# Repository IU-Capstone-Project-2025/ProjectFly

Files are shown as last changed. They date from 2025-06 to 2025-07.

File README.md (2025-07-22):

# **Project Fly** 

🚀 *Reed Switch-Based Liquid Level Sesnor.*

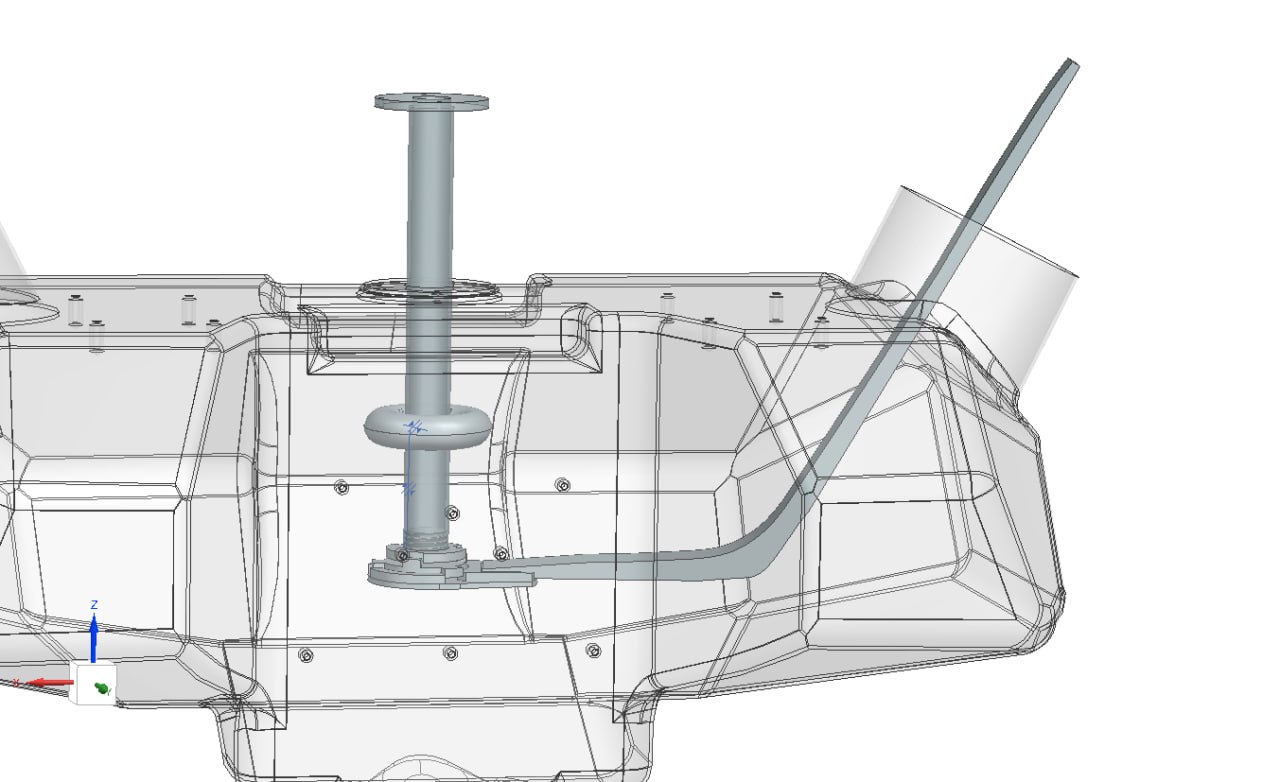
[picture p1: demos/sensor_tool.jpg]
Sensor with assembly tool inside of a tank


## 📌 Overview
A compact reed switch-based liquid level sensor designed for UAV-mounted tanks for agrochemicals. The sensor uses a magnetic float and hermetically sealed reed switches to reliably detect liquid levels in harsh environments.

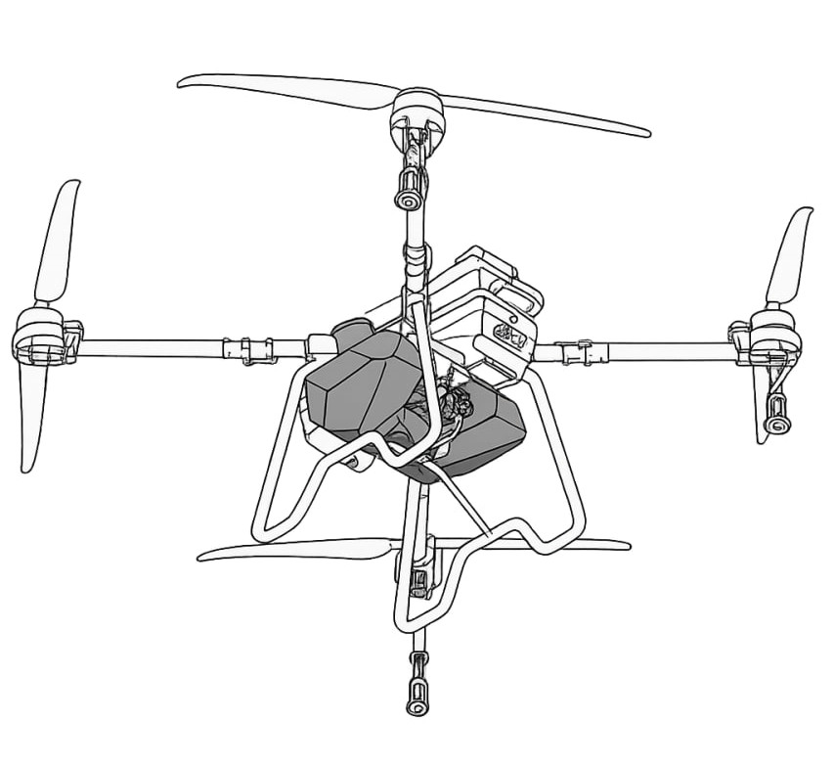
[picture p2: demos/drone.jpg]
Drone with tank


## 🔧 Key Features 
- **No calibration needed**: float does not depend on liquid type
- **Robust signal**: sliding window median filter
- **Easy to install**: special assembling tool
- **Low power consumption**

## 🛠️ Hardware 
- **Key components**: Reed Switches 4x28 mm NC
- **Microcontroller**: STM32F103C8T6
- **Output**: Digital signal (UART)
- **Power**: 3.3V-5V

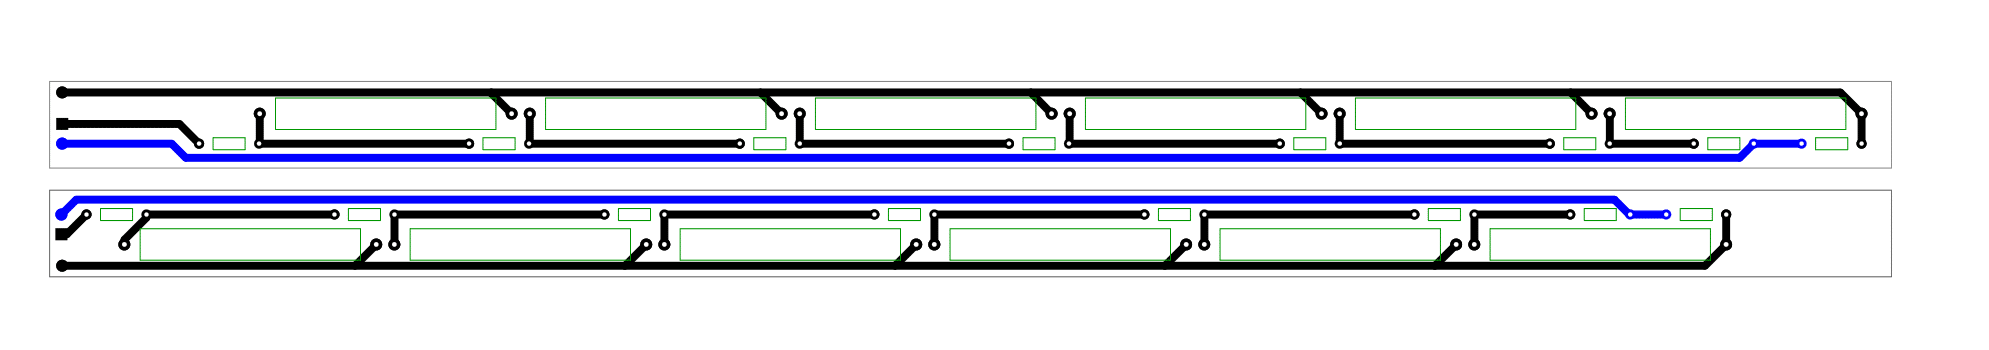
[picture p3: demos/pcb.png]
PCB


## 📚 Documentation
- [**Schematics sheet**](docs/schematics.pdf)
- [**Schematics description**](docs/schematics.md)
- [**Assembly guide**](docs/assembly.md)

## 📂 Project Structure
```
ProjectFly
├── cad         # 3D models
├── demos       # Demonstrations videos and images
├── docs        # Project documentation
├── firmware    # Embedded code
│   ├── arduino # Arduino-compatible firmware (for prototyping)
│   └── stm32   # STM32-optimized firmware (production version)
├── hardware    # Electronics design files
│   └── pcb     # PCB schematics and layouts
└── tests       # Validation scripts
```

## 👥 Team Members
### Hardware
- **Dmitriy Vizitei** - team leader, prototyping
- **Senya Belykh** - schematics, PCB design
- **Anas Hamrouni** - CAD modeling & design
### Software
- **Dmitry Ryabov** - programming, testing
### Documentation 
- **Andrew Pavlov** - documentation, reports

## 🛠 **Build && Install Guide**  
**Docker** ([Install Guide](https://docs.docker.com/engine/install/)) <br>
In terminal:  
1) `docker-compose build` 
2) `docker-compose up`

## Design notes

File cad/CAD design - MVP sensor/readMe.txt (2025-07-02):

Here is name & description of parts of the floating mechanism, parts consisting of multiple parts are grouped together.
In the directory you find two assembly files and separate part files.
rodTankAssembly is the global assembly file containing all the parts.

Float: (consists of two parts to be assembled with snap joints, housing up to 4 magnets)
- part1name: float: first part of the float
- part2name: float - Copie: second part of the float

Bottom cap:
- part3name: bottomcap: serves to block float from escaping from the rod column

Sensor rod (shaft)
- part4name: rod2: main vertical column of the sensor to guide the float and serves as housing of IC with reed sensors (still low fidelity, no fixing of IC yet)

Assembling tool (consists of three parts to be glued together): serves to fix the bottom cap
- part5name: toolHandler: first part of assembling tool
- part6name: toolHandle2: second part of assembling tool
- part7name: tool: third part of assembling tool

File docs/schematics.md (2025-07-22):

# Electrical Circuit
The electrical circuit of the device consists of six normally closed (NC) reed switches (4x28 mm) that connect power and signal lines. A 10 kΩ resistor is placed between each reed switch to detect which one is closed using the voltage divider rule. A current-limiting resistor is placed before the first reed switch to prevent a short circuit. A separating resistor is placed after the last reed switch to distinguish between the last reed switch being closed and no switch being closed. A 100 kΩ resistor is connected between the signal line and ground to suppress contact bouncing. The circuit operates at 3.3 V.

# PCB Design
The printed circuit board (PCB) has a length matching the tank length (234 mm), which fits six reed switches with 0.85 mm spacing between leads, and a minimum possible width of 11 mm. The trace width is 1 mm for reliability and ease of manufacturing. The final device consists of two identical PCBs, but with the reed switches offset by 14 mm (half the length of a reed switch) relative to each other. This allows dual verification of magnet position and eliminates blind spots between reed switches on the opposite PCB.

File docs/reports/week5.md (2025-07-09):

---
title: "Week #5"
---

# **Week #5**

## Team

### **Team Members**

| Team Member							| Telegram Alias	| Email Address 					| Track												| Responsibilities |
|---|---|---|---|---|
| Dmitriy Vizitei (Lead)				| @otkisaev			| d.vizitei@innopolis.university 	| Low level (embedded) + Electric circuit engineer + testing  | Project coordination, task delegation, programming and testing prototypes |
| Senea Belykh							| @SenyaZenya		| s.belykh@innopolis.university		| Low level (embedded) + Electric circuit engineer	| Programming and testing prototypes |
| Dmitry Ryabov							| @theDioxider		| d.ryabov@innopolis.university 	| Low level (embedded) 								| Programming |
| Anas Hamrouni							| @reachnasta		| a.hamrouni@innopolis.university | Design engineer 									| Designing 3D models |
| Andrew Pavlov							| @chaleshka_0		| and.pavlov@innopolis.university	| Tech writer 										| Document the work and write reports |

## Feedback

Through Alexander Maloletov (Director of the Robotics Development Center in Innopolis), we agreed that upon completion of the order, the project participants will receive a lump sum payment.

## Iteration & Refinement

### Performance & Stability

When the magnet slides post reed switches, there is a chance to get a value equal to 0. This is due to the current solution and design. There is a metric associated with the gaps between switches. <br />
An iteration solution would be to reduce the size of reed switches to such an extent that a negligibly small gap between the switches is reached, which would guarantee a constant and unambiguously set position of the float.

# Weekly commitments

## Individual contribution of each participant

| Member					| Contribution					|
|---|---|
| Dmitriy Vizitei			| Assembly of a product, communication, testing: [photo](https://drive.google.com/file/d/11ErTu5s1axHB51JZw7vPIAQcNcZdXoS1/view?usp=drive_link), [video 1](https://drive.google.com/file/d/17mmQQElqiJNetmurcGpcXXFE-Ebcmi8j/view?usp=drive_link), [video 2](https://drive.google.com/file/d/1X96Me4vulu15EC3oLPyxjKNYTdaBQLdP/view?usp=drive_link), [video 3](https://drive.google.com/file/d/1RMR0l2JPTSWMmnUTkXt8X2qB1T35l_1s/view?usp=drive_link) |
| Senea Belykh				| [Littel change design of board and design of a microcontroller board](https://github.com/IU-Capstone-Project-2025/ProjectFly/commit/9250cefd38d36df9182ef802b712d2c060db03d2) | 
| Dmitry Ryabov				| Determining reed switch based on voltage: [photo](https://drive.google.com/file/d/1ix-wG_TddyOyOhTqer4dDWPdwUh-kQOK/view?usp=drive_link), [commit 1](https://github.com/IU-Capstone-Project-2025/ProjectFly/commit/e2bc04ccc3fc08e8e42fd3654ed2149dc4a043e4), [commit 2](https://github.com/IU-Capstone-Project-2025/ProjectFly/commit/748511da521208b3848574d846316bceeffb3a55) |
| Anas Hamrouni				| [PCB design + review of dimensions](https://github.com/IU-Capstone-Project-2025/ProjectFly/commit/1565ed656107ac8c0a5cf2ffb28c307ee85f2cba) |
| Andrew Pavlov				| [5nd week report.](https://github.com/IU-Capstone-Project-2025/ProjectFly/blob/main/docs/reports/week5.md) |

## Plan for Next Week

- Build the microcontroller board
- Complete the prototype assembly
- Сontact the customer to confirm our product solution

## Confirmation of the code's operability

We confirm that the code in the main branch:
- [x] In working condition.
- [x] Run via docker-compose (or another alternative described in the `README.md`).

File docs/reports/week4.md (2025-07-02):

---
title: "Week #4"
---

# **Week #4**

## Team

### **Team Members**

| Team Member							| Telegram Alias	| Email Address 					| Track												| Responsibilities |
|---|---|---|---|---|
| Dmitriy Vizitei (Lead)				| @otkisaev			| d.vizitei@innopolis.university 	| Low level (embedded) + Electric circuit engineer + testing  | Project coordination, task delegation, programming and testing prototypes |
| Senea Belykh							| @SenyaZenya		| s.belykh@innopolis.university		| Low level (embedded) + Electric circuit engineer	| Programming and testing prototypes |
| Dmitry Ryabov							| @theDioxider		| d.ryabov@innopolis.university 	| Low level (embedded) 								| Programming |
| Anas Hamrouni							| @reachnasta		| a.hamrouni@innopolis.university | Design engineer 									| Designing 3D models |
| Andrew Pavlov							| @chaleshka_0		| and.pavlov@innopolis.university	| Tech writer 										| Document the work and write reports |

## CI/CD

During CI/CD, we encountered the problem that the github workflow does not have a compilation environment for our product, so we did manual tests on cubeIDE.

### Links to CI/CD configuration files

https://github.com/IU-Capstone-Project-2025/ProjectFly/blob/main/.github/workflows/c-linter.yaml

## Vibe Check

The team leader is on sick leave, and the rest of the team is healthy. <br />
Due to logistical problems, the laser needed for the work was delivered to us very late in time for the deadline, which caused a lot of stress during its setup and operation in the last hours before the deadline.

# Weekly commitments

## Individual contribution of each participant

| Member					| Contribution					|
|---|---|
| Dmitriy Vizitei			| Testing: [photo 1](https://drive.google.com/file/d/11sWm9Eje6SpBsuDrlUKM9gq9MjP24NQu/view?usp=drive_link), [photo 2](https://drive.google.com/file/d/1dNQqF_wJioakaVgUDXrWjnx1O2QSEEL4/view?usp=drive_link); laying out the board using laser: [video 1](https://drive.google.com/file/d/1wMU_KEni9PQ2VG3ThoixvVIlINiCmWOo/view?usp=drive_link), [video 2](https://drive.google.com/file/d/13v9Dhd8rFhSDY7FK-wtBonQAqTI9EYGV/view?usp=drive_link), [photo](https://drive.google.com/file/d/1k83NPXRmFJaZUlnCxQowFRZGzRzlfGT7/view?usp=drive_link) |
| Senea Belykh				| The renewed version of the board: [screenshot 1](https://drive.google.com/file/d/1f35pPph8MtAH_zsE1N_wpZU_w1E1n0Zs/view?usp=drive_link), [screenshot 2](https://drive.google.com/file/d/1TuTwNzNpZY1UzZ-rh-VTb_SV1s4rwtpJ/view?usp=drive_link), [files](https://github.com/IU-Capstone-Project-2025/ProjectFly/commit/5295f774d12a0047f9f7b59432f5d1f2cc4458eb); [testing](https://drive.google.com/file/d/1BBwjxaTWTiUZHPBcxWp0rQVh082nHvK7/view?usp=drive_link) |
| Dmitry Ryabov				| [CI/CD](https://github.com/IU-Capstone-Project-2025/ProjectFly/blob/main/.github/workflows/c-linter.yaml), [filter (embedded development)](https://github.com/IU-Capstone-Project-2025/ProjectFly/commit/508749f63c032bdbdd70469d089fd19ae9c99970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) |
| Anas Hamrouni				| The design of lever, the renewed design of float, design of the rod: [photo 1](https://drive.google.com/file/d/11sWm9Eje6SpBsuDrlUKM9gq9MjP24NQu/view?usp=drive_link), [photo 2](https://drive.google.com/file/d/1dNQqF_wJioakaVgUDXrWjnx1O2QSEEL4/view?usp=drive_link), [files](https://github.com/IU-Capstone-Project-2025/ProjectFly/commit/2ea619bedeee6b55bfc94a4936219a47339772bb) |
| Andrew Pavlov				| [4nd week report.](https://github.com/IU-Capstone-Project-2025/ProjectFly/blob/main/docs/reports/week4.md) |

## Plan for Next Week

- Layout the final pcb using laser
- Assemble the renewed configuration of a product
- Connect the pcb to the layout of reed switches

## Confirmation of the code's operability

We confirm that the code in the main branch:
- [X] In working condition.
- [X] Run via docker-compose (or another alternative described in the `README.md`).

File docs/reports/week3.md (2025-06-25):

---
title: "Week #3"
---

# **Week #3**

## Team

### **Team Members**

| Team Member							| Telegram Alias	| Email Address 					| Track												| Responsibilities |
|---|---|---|---|---|
| Dmitriy Vizitei (Lead)				| @otkisaev			| d.vizitei@innopolis.university 	| Low level (embedded) + Electric circuit engineer  | Project coordination, task delegation, programming and testing prototypes |
| Senea Belykh							| @SenyaZenya		| s.belykh@innopolis.university		| Low level (embedded) + Electric circuit engineer	| Programming and testing prototypes |
| Dmitry Ryabov							| @theDioxider		| d.ryabov@innopolis.university 	| Low level (embedded) 								| Programming |
| Anas Hamrouni							| @reachnasta		| a.hamrouni@innopolis.university | Design engineer 									| Designing 3D models |
| Andrew Pavlov							| @chaleshka_0		| and.pavlov@innopolis.university	| Tech writer 										| Document the work and write reports |

## Implemented MVP features
- Functional fragment of sensor
- Programmed stm microcontroller that read, process and output signals from the sensor
- 3d model of sensor road and float with assembly tool
- Finished PCB layout

## Demonstration of the working MVP

https://github.com/user-attachments/assets/4fa052ff-b1a2-4596-b420-3efbf912d3e5

## Internal demo

The demonstration shows a fragment of the sensor consisting of two parallel circuits with reed switches. The second circuit is needed to validate the readings. Readings from two circuits are displayed separately on the screen.
In the future, with the help of a filter and two readings, a smooth and reliable output of values will be realized.

# Weekly commitments

## Individual contribution of each participant

| Member					| Contribution					|
|---|---|
| Dmitriy Vizitei			| [Build and testing of the float sensor](https://github.com/IU-Capstone-Project-2025/ProjectFly/blob/main/docs/reports/week3_demo.mp4)	|
| Senea Belykh				| Design of a printing board model: [.dip file of model](https://drive.google.com/file/d/1kAshYWK63EGtSO8ugL8LIpLLuq3zHijo/view?usp=drive_link), [Screenshot 1](https://drive.google.com/file/d/1b59gKXb-_gpLtJmoub-71Or28Qxjg9nt/view?usp=drive_link), [Screenshot 2](https://drive.google.com/file/d/1cMnjLT8AdKEfaEngB_d79zmb4BKwSN_p/view?usp=drive_link), [Screenshot 3](https://drive.google.com/file/d/19lfl12A_gvJT9DxeMLiNG9lB-w_u033m/view?usp=drive_link), [Screenshot 4](https://drive.google.com/file/d/15qXjzGLoRry6YyHDq0xQBWc0gWb6dqjc/view?usp=sharing)	|
| Dmitry Ryabov				| [Data processing and multitasking implementation](https://github.com/IU-Capstone-Project-2025/ProjectFly/commit/427cdca47f92fd35336689fed5b88d71be1657ca)	|
| Anas Hamrouni				| CAD design for MVP float sensor and and its installation: [Screenshot 1](https://drive.google.com/file/d/1yXhJFeNlo0ktXdDd30qICJDR3P5ZgBRc/view?usp=drive_link), [Screenshot 2](https://drive.google.com/file/d/1Cs98SicpZ4TfVprqYWIeNAE5lt_2MkrX/view?usp=drive_link), [Screenshot 3](https://drive.google.com/file/d/1mO2JWQUNWl51_XnYHGpag1vgucJC9s4t/view?usp=drive_link), [Screenshot 4](https://drive.google.com/file/d/1EVLHVlt_bsYl2PFsscmXYxY9q6P1DE29/view?usp=sharing), [Screenshot 5 (The brown color is one piece to be assembled as a tool) ](https://drive.google.com/file/d/1q62NgHWZDSAhbYw4ZfM8Jk9xgEBASD9l/view?usp=drive_link), [archive with models of parts](https://drive.google.com/file/d/1Xy0XBJnHxUWf5-DdJJCfNiPBmoh62PsU/view?usp=drive_link)	|
| Andrew Pavlov				| [3nd week report.](https://github.com/IU-Capstone-Project-2025/ProjectFly/blob/main/docs/reports/week3.md)	|

## Plan for Next Week

- Lay out the board
- Prepare MVP 
- Test the MVP 
- Analyze the numerical data after the test and consider alternative approaches based on it

## Confirmation of the code's operability

We confirm that the code in the main branch:
- [X] In working condition.
- [X] Run via docker-compose (or another alternative described in the `README.md`).

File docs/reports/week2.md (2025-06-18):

---
title: "Week #2"
---

# **Week #2**

## Team

### **Team Members**

| Team Member							| Telegram Alias	| Email Address 					| Track												| Responsibilities |
|---|---|---|---|---|
| Dmitriy Vizitei (Lead)				| @otkisaev			| d.vizitei@innopolis.university 	| Low level (embedded) + Electric circuit engineer  | Project coordination, task delegation, programming and testing prototypes |
| Senea Belykh							| @SenyaZenya		| s.belykh@innopolis.university		| Low level (embedded) + Electric circuit engineer	| Programming and testing prototypes |
| Dmitry Ryabov							| @theDioxider		| d.ryabov@innopolis.university 	| Low level (embedded) 								| Programming |
| Anas Hamrouni							| @reachnasta		| a.hamrouni@innopolis.university | Design engineer 									| Designing 3D models |
| Andrew Pavlov							| @chaleshka_0		| and.pavlov@innopolis.university	| Tech writer 										| Document the work and write reports |

## Detailed Requirements Elaboration

### Prioritized backlog

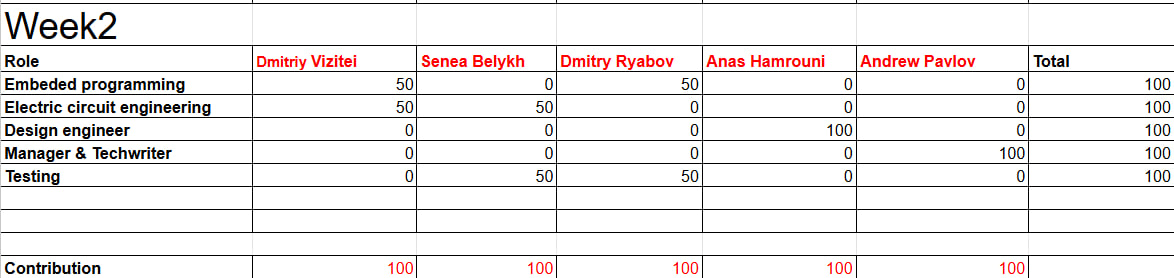
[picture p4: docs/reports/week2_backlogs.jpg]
Backlog


More about that check [here (Individual contribution of each participant)](#individual-contribution-of-each-participant)

## Project specific progress

### Embeded programming
 Managed to read measurements from the new prototype of sensor based on stm and reed configuration.
 
 ##### *Links*:
 - [video](https://drive.google.com/file/d/1tDcIl50uG16ULDPnCgHA8W5yxoyPV0qn/view?usp=drive_link)
 - [commit 1](https://github.com/IU-Capstone-Project-2025/ProjectFly/commit/f93522ddb09a518377ced257cc0ca16c6add2b1f)
 - [commit 2](https://github.com/IU-Capstone-Project-2025/ProjectFly/commit/e084e92ea104956475aa945d4a9cade105bdb73c)

<br/>
<br/>

### Electric circuit engineering
 Build the prototype based on reed switch

 ##### *Links*:
 - [schema](https://drive.google.com/file/d/1HSIqzhiNN1nDQKsxPV_4JEf09wa4fA4u/view?usp=drive_link)
 - [builded scheme](https://drive.google.com/file/d/1XPFuSay2cHmU6ANBiu6EqrAynp7D94Xp/view?usp=drive_link)

<br/>
<br/>

### Design engineer
#### 1. Define functional and user requirements of the rod: 
- Simple & 3d printable geometry
- Respect shape dimensions to fit the tank
- Ease of installation
- Safety and efficiency of use 

#### 2. Sketching the model:
- Ensure to provide 3d printable geometry
- Design robust shape despite small dimension
- Added screw threading to fix small shape easily without special tools
- Built a safe and efficient solution by avoiding changing shape of the tank and requiring simple drilling to place the rod with keeping the tank sealed.

 ##### *Links*:
 - [Screenshot 1](https://drive.google.com/file/d/1L9kOTLYdC7mNY9wW7mFL8em9XUuGiUwT/view?usp=drive_link)
 - [Screenshot 2](https://drive.google.com/file/d/1gHUbHs0_TNIRGTnDAtzoiVuIBHDGAfwj/view?usp=drive_link)
 - [file 1](https://drive.google.com/file/d/1nWXCW6NQID7t2FsywJsJTqwMTLUtGRwR/view?usp=drive_link)
 - [file 2](https://drive.google.com/file/d/1oYTtV5gna4aSWWOiLER292Gw-_cxK6or/view?usp=drive_link)

<br/>
<br/>

### Testing
Testing prototypes

 ##### *Links*:
 - [video](https://drive.google.com/file/d/1Viy6Q0saY_VFVdwo4Y1-elQ6-YxZEiJ0/view?usp=drive_link)
 - [schema](https://drive.google.com/file/d/1ElpVAXV8CM7XJ8-GV-PHEquDS3nxepYG/view?usp=drive_link)
 - [commit](https://github.com/IU-Capstone-Project-2025/ProjectFly/commit/0b85bc00f4705b56a24b432282a6310fd2ffb4f2)
<br/>
<br/>

### Manager
Clarification from the customer: *He prefers that we do not go into the mathematical model of the drone to solve this problem.*

<br/>
<br/>

# Weekly commitments

## Individual contribution of each participant

| Member					| Contribution					|
|---|---|
| Dmitriy Vizitei			| [Planning the work](https://drive.google.com/file/d/1gMR6xSsX36B3hY9kbOCmtgMwcS75k4nC/view?usp=drive_link), testing one of the prototypes: [video](https://drive.google.com/file/d/1Viy6Q0saY_VFVdwo4Y1-elQ6-YxZEiJ0/view?usp=drive_link), [schema](https://drive.google.com/file/d/1ElpVAXV8CM7XJ8-GV-PHEquDS3nxepYG/view?usp=drive_link), [commit](https://github.com/IU-Capstone-Project-2025/ProjectFly/commit/0b85bc00f4705b56a24b432282a6310fd2ffb4f2).	|
| Senea Belykh				| Build the prototype based on [reed switch](https://en.wikipedia.org/wiki/Reed_switch): [schema](https://drive.google.com/file/d/1HSIqzhiNN1nDQKsxPV_4JEf09wa4fA4u/view?usp=drive_link), [builded scheme](https://drive.google.com/file/d/1XPFuSay2cHmU6ANBiu6EqrAynp7D94Xp/view?usp=drive_link).	|
| Dmitry Ryabov				| Managed to read measurements from the new prototype of sensor based on stm and reed configuration: [video](https://drive.google.com/file/d/1tDcIl50uG16ULDPnCgHA8W5yxoyPV0qn/view?usp=drive_link), [commit 1](https://github.com/IU-Capstone-Project-2025/ProjectFly/commit/f93522ddb09a518377ced257cc0ca16c6add2b1f), [commit 2](https://github.com/IU-Capstone-Project-2025/ProjectFly/commit/e084e92ea104956475aa945d4a9cade105bdb73c). [Geometric implementation of first prototype](https://drive.google.com/file/d/1gd1Zq0q2f0FHHBFnNQjB2sdK0_8jG9m8/view?usp=drive_link). 	|
| Anas Hamrouni				| Sensor installation design: [Screenshot 1](https://drive.google.com/file/d/1L9kOTLYdC7mNY9wW7mFL8em9XUuGiUwT/view?usp=drive_link), [Screenshot 2](https://drive.google.com/file/d/1gHUbHs0_TNIRGTnDAtzoiVuIBHDGAfwj/view?usp=drive_link), [file 1](https://drive.google.com/file/d/1nWXCW6NQID7t2FsywJsJTqwMTLUtGRwR/view?usp=drive_link), [file 2](https://drive.google.com/file/d/1oYTtV5gna4aSWWOiLER292Gw-_cxK6or/view?usp=drive_link).	|
| Andrew Pavlov				| [2nd week report.](https://github.com/IU-Capstone-Project-2025/ProjectFly/blob/main/docs/reports/week2.md)	|

## Plan for Next Week

- Design a board with a double sequence of reed sensors
- Finalize the prototype of the rod sensor
- Print a prototype of the sensor rod
- Build the entire circuit, isolating the electronics from the liquid, and move the controller to the outside of the tank
- Сheck the functionality of the product

## Confirmation of the code's operability

We confirm that the code in the main branch:
- [x] In working condition.
- [x] Run via docker-compose (or another alternative described in the `README.md`).

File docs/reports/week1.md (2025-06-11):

---
title: "Week #1"
---

# Week #1

## Project description

### Project name: Project fly

**Code repository**: https://github.com/IU-Capstone-Project-2025/ProjectFly

This project is a request for the development of a solution for agricultural drone use. 
The task is involve development of the a system for measuring the liquid level in a UAV tank for spraying agricultural crops.

### **Team Members**

| Team Member							| Telegram Alias	| Email Address 					| Track												| Responsibilities |
|---|---|---|---|---|
| Dmitriy Vizitei (Lead)				| @otkisaev			| d.vizitei@innopolis.university 	| Low level (embedded) + Testing engineer  			| Project coordination, task delegation, programming and testing prototypes |
| Senea Belykh							| @SenyaZenya		| s.belykh@innopolis.university		| Low level (embedded) + Electric circuit engineer	| Programming and testing prototypes |
| Dmitry Ryabov							| @theDioxider		| d.ryabov@innopolis.university 	| Low level (embedded) + Electric circuit engineer 	| Programming and testing prototypes |
| Anas Hamrouni							| @reachnasta		| a.hamrouni@innopolis.university | Design engineer 									| Designing 3D models |
| Andrew Pavlov							| @chaleshka_0		| and.pavlov@innopolis.university	| Tech writer 										| Document the work and write reports |

## Brainstorming

### Ideas during brainstorming

During the brainstorming, several sensor options were proposed:
- A conventional float sensor
- A sensor that detects the presence of liquid based on the resistance of the liquid

### Brief market research / problem validation

As drones become more and more popular, they are becoming more widely used in various industries. 
In this case, we received a request from the customer with a problem with UAV tank on agricultural drone, that he can't solve more then year.

## Basic requirements

### Target users and their primary needs

People that use drones in the agricultural industry.

### User stories

The customer is faced with the problem that the liquid from a UAV tank stops being transferred, although there is still enough liquid in a UAV tank.

### Initial scope

Development of sensor prototypes using an existing board. 
Development of an embedded sensor. 
Testing prototypes on the raw version of the tank.

## Tech-stack

| Field					| Stack							|
|---|---|
| Embeded programming	| C/C++, Cube IDE, Arduino IDE	|
| Design engineer		| NX Seimens					|
| Sensors Mechanics		| Math + physics				|

# Weekly commitments

## Individual contribution of each participant

| Member					| Contribution					|
|---|---|
| Dmitriy Vizitei			| Core repository structure: [initialized repository](https://github.com/IU-Capstone-Project-2025/ProjectFly/commit/19ece8dd689269b8877637c0cdd9e248106d6f66); [created README with min. info](https://github.com/IU-Capstone-Project-2025/ProjectFly/commit/e50a447534157cbb9bf82c0cbb02ca23cbfe9245), meetings organization, [coding for sonar sensor](https://drive.google.com/file/d/1LidOm8-sfzgR6SBzXvL8MPFwJuZYcI2e/view) and [drew conclusions](https://drive.google.com/file/d/1uPqIGXmfji8wScobm7uN8mmkmz8bqaa-/view)  |
| Senea Belykh				| Experiments with sonar sensor and potential measure across different liquids: [1 photo](https://drive.google.com/file/d/1iks-ICr-Jj6YDTbC_7g15NeuBZ0NiNc6/view), [2 photo](https://drive.google.com/file/d/1U9N12xxdES-TP-YdTxnyD7aCKuFkxgFy/view) |
| Dmitry Ryabov				| Developing the sketch model for float - measuring solution and mechanical approach to it: [1 photo](https://drive.google.com/file/d/1B1FFSR7dEByimEyTBBDzXpCQsAIk3exs/view), [2 photo](https://drive.google.com/file/d/1paRiFeqJcF4dm9tiB3F9iAVMbtcniBE8/view) |
| Anas Hamrouni				| Assembly and 3d printing of prepared slice of given fuel tank: [1 photo](https://drive.google.com/file/d/1lN4BLDHryvy0sIiT8JNs3DoKl2EEyYCS/view), [2 photo](https://drive.google.com/file/d/1RkKiIEnV-A94Wn-GcgxEGb1zZ3Kr0lAV/view), [3 photo](https://drive.google.com/file/d/1N7Sre0JA2KTpTBYblD5QK42kd-GkthfW/view), [4 photo](https://drive.google.com/file/d/1aHhj54TxobaaM10KJL29bydH0yrErl8g/view), [5 photo](https://drive.google.com/file/d/1IxX14vZsZe_04kBdniVQ5BPaV8_wYsOM/view)|
| Andrew Pavlov				| Designed the repository: [made simple dockerfile && docker-compose, filled README](https://github.com/IU-Capstone-Project-2025/ProjectFly/commit/1e72d54a43d55706654bb48358b227a1712d22fd) |

## Confirmation of the code's operability

We confirm that the code in the main branch:
- [x] In working condition.
- [x] Run via docker-compose (or another alternative described in the `README.md`).

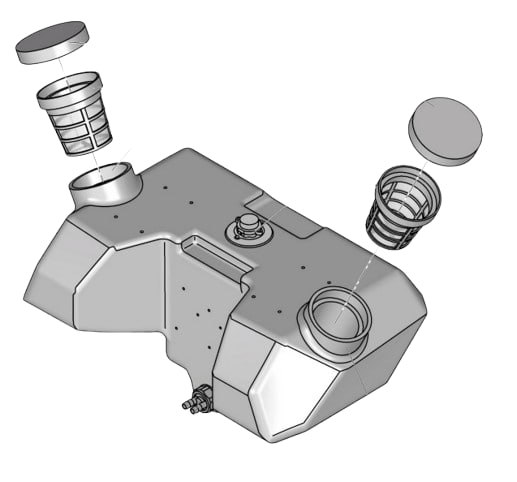
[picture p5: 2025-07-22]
demos/tank.jpg

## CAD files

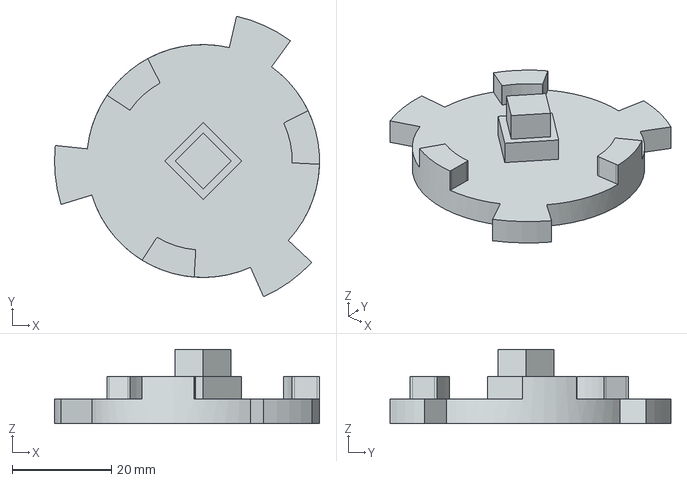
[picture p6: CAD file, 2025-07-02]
cad/mvp print1/tool.stp
53.5 x 56.6 x 15.0 mm

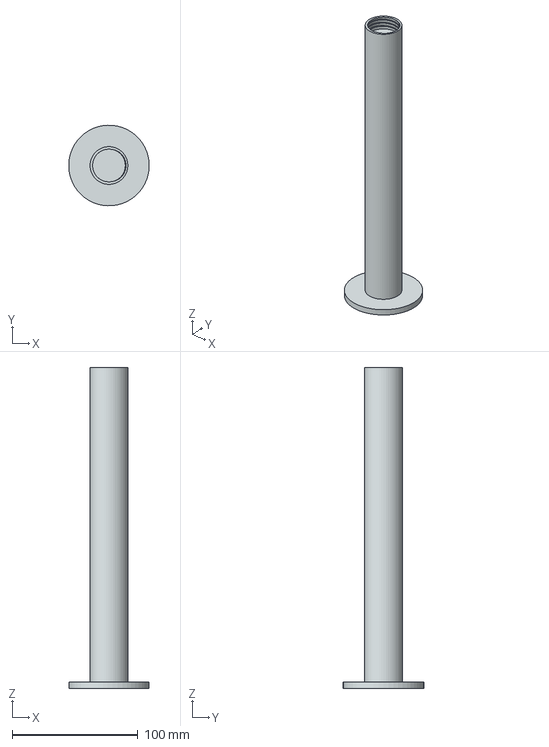
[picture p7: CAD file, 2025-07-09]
cad/mvp print2/rod2.stp
63.9 x 64.0 x 255.0 mm

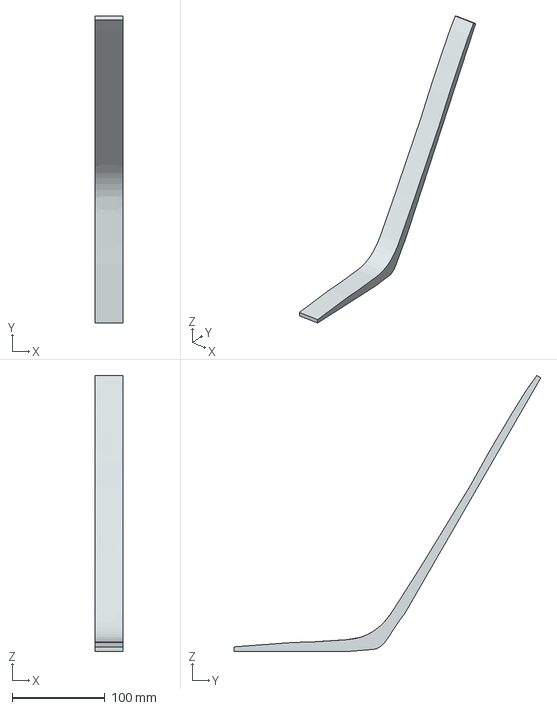
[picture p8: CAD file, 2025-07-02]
cad/mvp print1/toolHandler.stp
30.0 x 330.0 x 296.9 mm

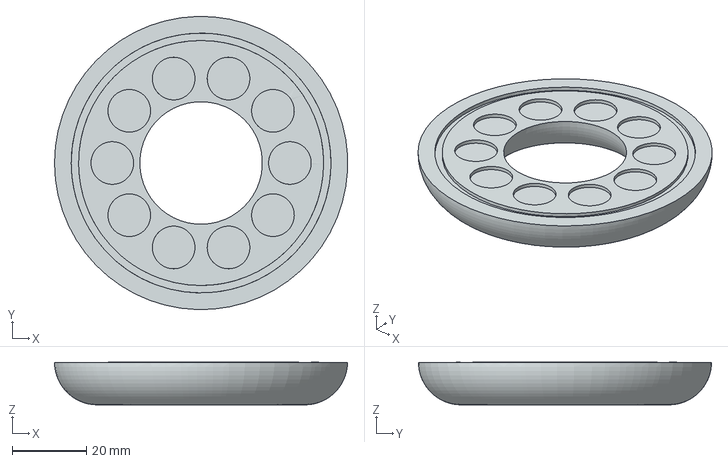
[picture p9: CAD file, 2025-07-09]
cad/mvp print2/floatWithGroove.stp
78.9 x 79.0 x 11.5 mm

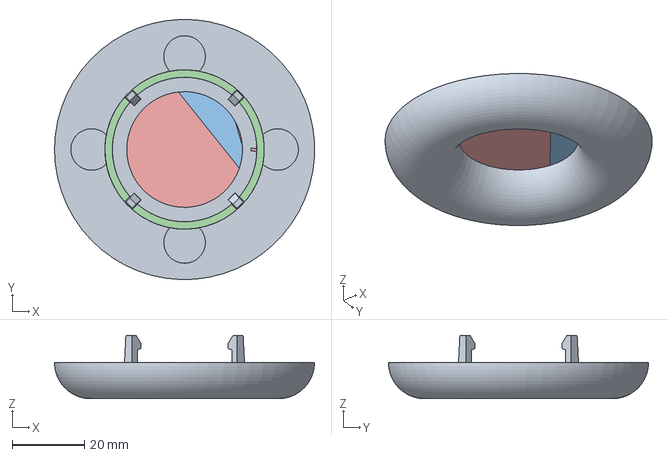
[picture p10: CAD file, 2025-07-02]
cad/mvp print1/float.stp
72.0 x 72.0 x 17.6 mm

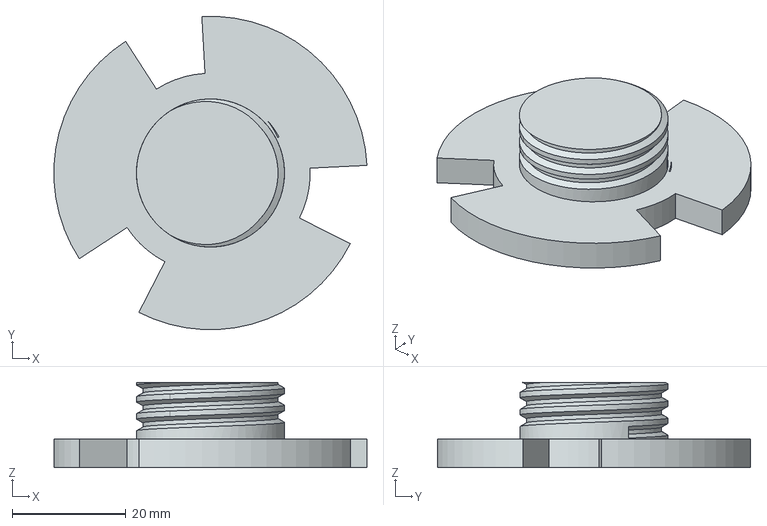
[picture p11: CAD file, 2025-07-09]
cad/mvp print2/bottomCap.stp
54.9 x 54.9 x 15.0 mm

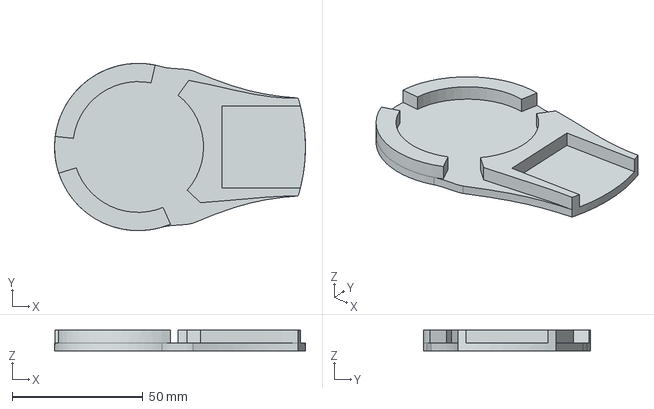
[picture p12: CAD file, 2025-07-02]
cad/mvp print1/toolHandle2.stp
96.0 x 64.0 x 8.00 mm

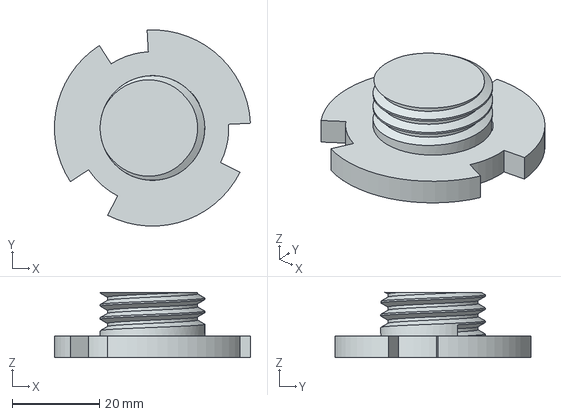
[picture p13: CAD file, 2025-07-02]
cad/mvp print1/bottomCap.stp
44.9 x 44.9 x 15.0 mm

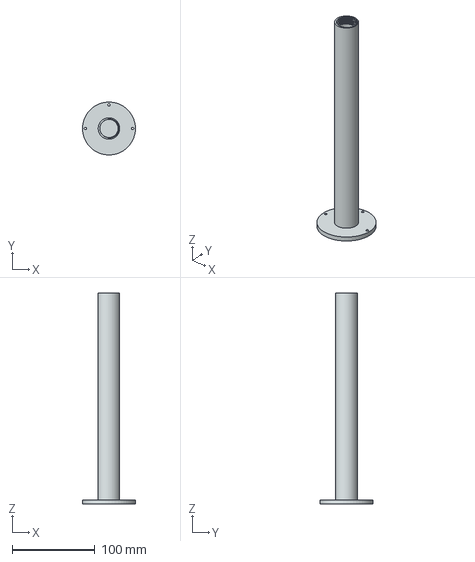
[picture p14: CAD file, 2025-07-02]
cad/mvp print1/rod2.stp
63.9 x 64.0 x 255.0 mm

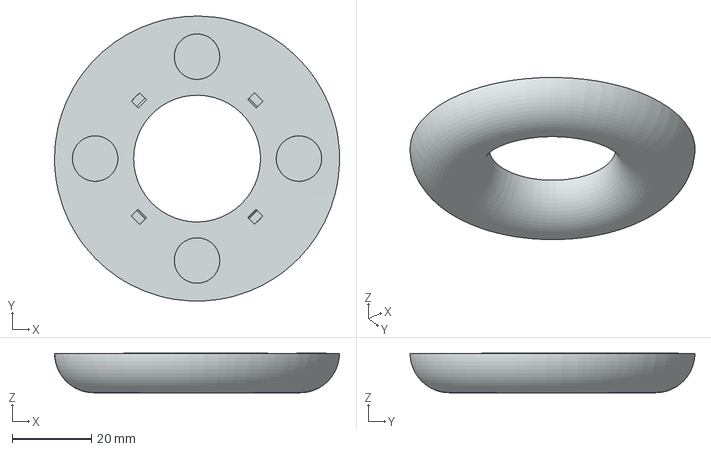
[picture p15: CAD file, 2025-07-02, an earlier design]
cad/mvp print1/float - Copie.stp
72.0 x 72.0 x 10.0 mm

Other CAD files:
cad/mvp print2/floatWithoutGroove.stp
cad/CAD design - MVP sensor/PCBassembly.prt
cad/CAD design - MVP sensor/bottomCap.prt
cad/CAD design - MVP sensor/float - Copie.prt
cad/CAD design - MVP sensor/float.prt
cad/CAD design - MVP sensor/floatAssembly.prt
cad/CAD design - MVP sensor/model1.prt
cad/CAD design - MVP sensor/pcb.prt
cad/CAD design - MVP sensor/reedSwitch.prt
cad/CAD design - MVP sensor/rod.prt
cad/CAD design - MVP sensor/rod2.prt
cad/CAD design - MVP sensor/rodTankAssembly.prt
cad/CAD design - MVP sensor/terminal.prt
cad/CAD design - MVP sensor/tool.prt
cad/CAD design - MVP sensor/toolHandle2.prt
cad/CAD design - MVP sensor/toolHandler.prt
cad/CAD design - MVP sensor/Бак 40 Л127181.prt

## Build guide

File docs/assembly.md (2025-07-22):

# Setup instructions

1. Assemble the tool
2. Assemble the float
3. Attach the 'bottomCap' to the tool
4. Place the float on the 'bottomCap'
5. Enter the tool into the tank through the filling neck
6. Enter the rod into the tank from the top
7. Align the rod with Float and the 'bottomCap'
8. Hold the tool and turn the rod to screw together the rod and the 'bottomCap' 
9. Pull the tool from the filling neck
10. Fix the rod with screws and place in the PCB

## How to assemble the tool:
1. Glue the short side of toolHandler with toolHandler2
2. Align the 'tool' part with 'toolhandler2' so they fit and glue them together

## How to assemble the float:
1. Put some glue inside the groove of the float
2. Attach both parts

## How to assemble the board:
1. The two PCBs are stacked together with the reed switches facing outward and a dielectric spacer in between.
2. They are then placed inside a rod.
3. Power (VCC), ground (GND), and two signal lines are connected to a microcontroller board mounted on the top cover.

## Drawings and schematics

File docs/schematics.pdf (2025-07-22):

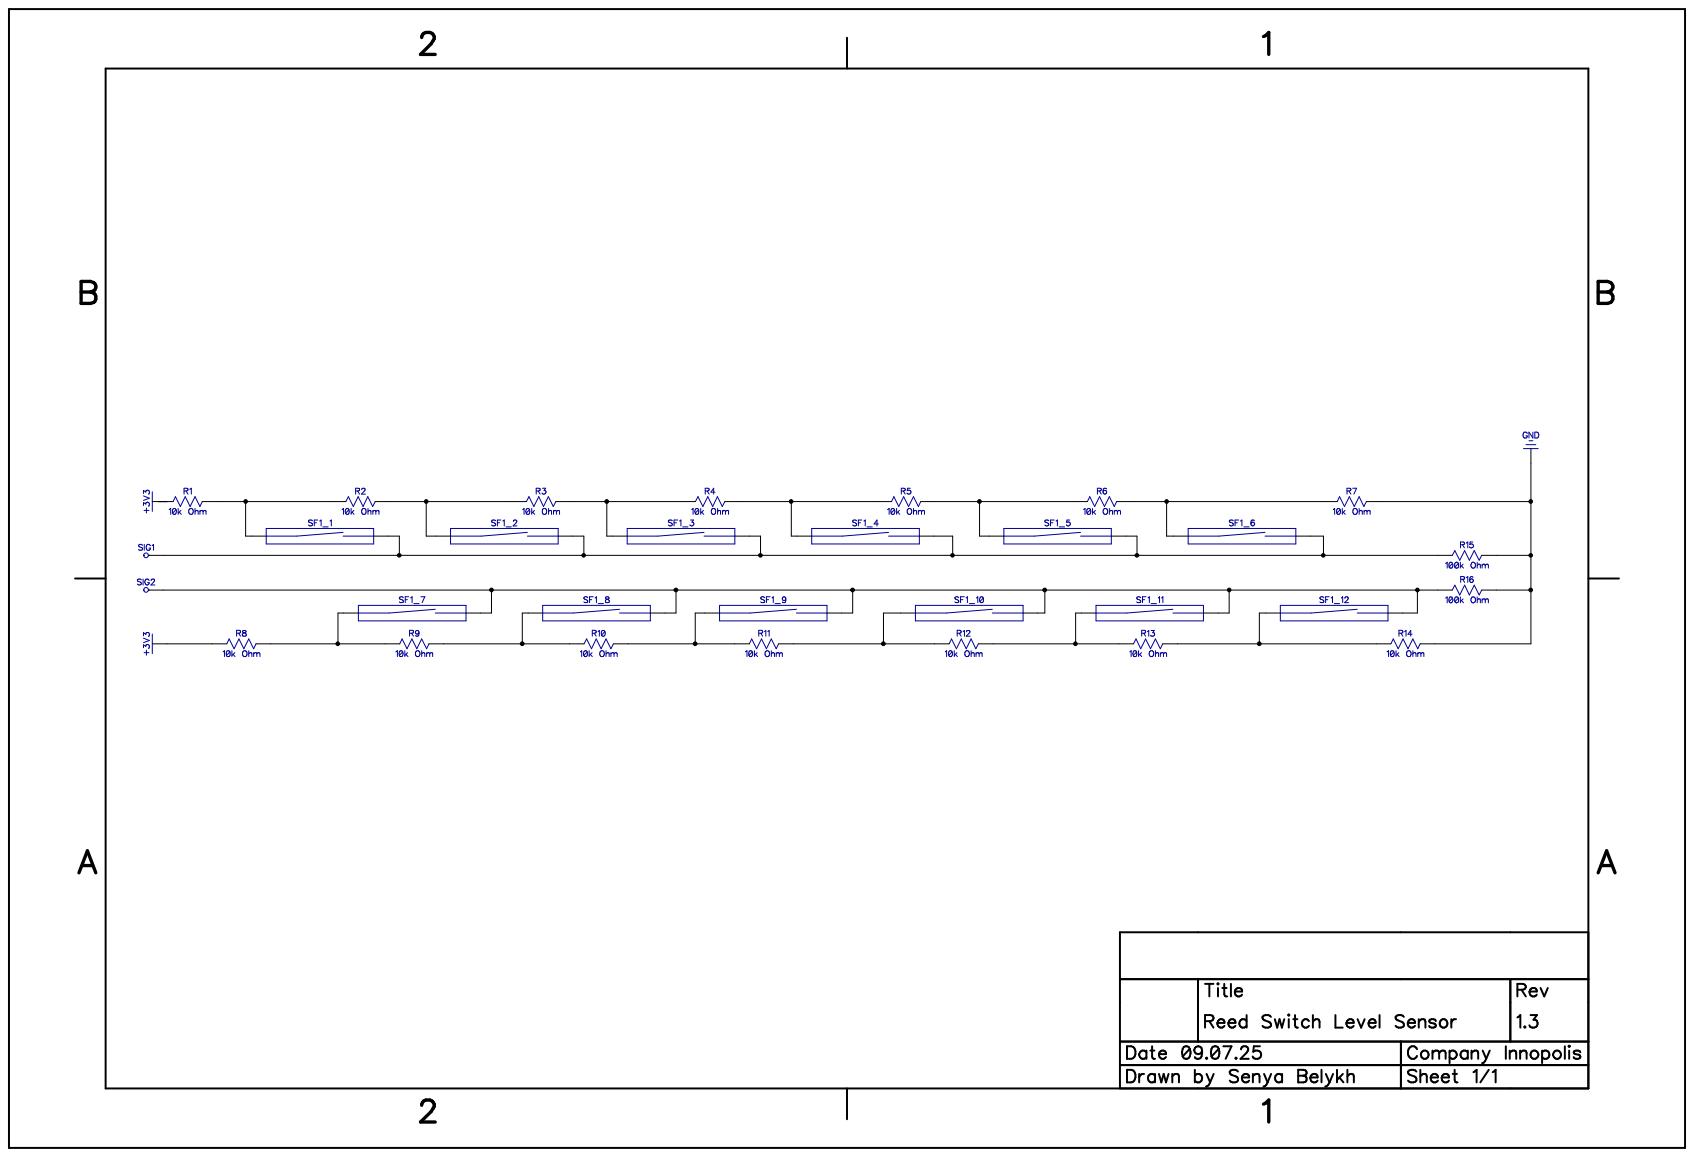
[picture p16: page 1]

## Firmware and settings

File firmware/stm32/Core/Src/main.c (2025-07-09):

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
/* Includes ------------------------------------------------------------------*/
#include "main.h"
#include "cmsis_os.h"

/* USER CODE BEGIN Includes */
#include <stdio.h>
#include <math.h>

/* USER CODE END Includes */

/* USER CODE BEGIN PD */
// max value ADC can output and its voltage
#define ADC_MAX_VALUE 4095
#define ADC_MAX_VOLTAGE 3.3
// number of measurements to store for averaging
#define ADC_WINDOW_SIZE 1024
// number of sensor lines
#define SENSOR_LINES 2

/* USER CODE END PD */

ADC_HandleTypeDef hadc1;
DMA_HandleTypeDef hdma_adc1;

TIM_HandleTypeDef htim3;
TIM_HandleTypeDef htim4;

USART_HandleTypeDef husart3;

/* Definitions for defaultTask */
osThreadId_t defaultTaskHandle;
const osThreadAttr_t defaultTask_attributes = {
  .name = "defaultTask",
  .stack_size = 128 * 4,
  .priority = (osPriority_t) osPriorityNormal,
};
/* Definitions for AdcTask */
osThreadId_t AdcTaskHandle;
const osThreadAttr_t AdcTask_attributes = {
  .name = "AdcTask",
  .stack_size = 128 * 4,
  .priority = (osPriority_t) osPriorityBelowNormal,
};
/* USER CODE BEGIN PV */

/* Configs */
/// Rescale each line to this boundaries
const int lineLength[SENSOR_LINES] = { 6, 6 };
const float sens_boundaries[SENSOR_LINES][2] = {
    {0., 90.},
	{10., 100.}
};
const float sens_max = 100.;

char buff[512];
uint32_t adcData[SENSOR_LINES];
uint32_t adcBuffer[SENSOR_LINES][ADC_WINDOW_SIZE] = {0};
uint64_t adcSum[SENSOR_LINES] = {0};

/* USER CODE END PV */

void SystemClock_Config(void);
static void MX_GPIO_Init(void);
static void MX_DMA_Init(void);
static void MX_TIM3_Init(void);
static void MX_TIM4_Init(void);
static void MX_ADC1_Init(void);
static void MX_USART3_Init(void);
void StartDefaultTask(void *argument);
void AdcRead(void *argument);

/* USER CODE BEGIN PFP */
void comprint(char *, int);
void setPWM(uint16_t, TIM_HandleTypeDef *, uint16_t);
void printMeasurements();

/* USER CODE END PFP */

/**
  * @brief  The application entry point.
  * @retval int
  */
int main(void)
{

  /* MCU Configuration--------------------------------------------------------*/

  /* Reset of all peripherals, Initializes the Flash interface and the Systick. */
  HAL_Init();

  /* Configure the system clock */
  SystemClock_Config();

  /* Initialize all configured peripherals */
  MX_GPIO_Init();
  MX_DMA_Init();
  MX_TIM3_Init();
  MX_TIM4_Init();
  MX_ADC1_Init();
  MX_USART3_Init();
  /* USER CODE BEGIN 2 */
  // blue LED brightness
  setPWM(1000, &htim4, TIM_CHANNEL_2);

  char buf[512];
  // clear COM port terminal
  comprint(buf, sprintf(buf, "\033[1J"));

  /* USER CODE END 2 */

  /* Init scheduler */
  osKernelInitialize();

  /* USER CODE BEGIN RTOS_MUTEX */
  /* add mutexes, ... */
  /* USER CODE END RTOS_MUTEX */

  /* USER CODE BEGIN RTOS_SEMAPHORES */
  /* add semaphores, ... */
  /* USER CODE END RTOS_SEMAPHORES */

  /* USER CODE BEGIN RTOS_TIMERS */
  /* start timers, add new ones, ... */
  /* USER CODE END RTOS_TIMERS */

  /* USER CODE BEGIN RTOS_QUEUES */
  /* add queues, ... */
  /* USER CODE END RTOS_QUEUES */

  /* Create the thread(s) */
  /* creation of defaultTask */
  defaultTaskHandle = osThreadNew(StartDefaultTask, NULL, &defaultTask_attributes);

  /* creation of AdcTask */
  AdcTaskHandle = osThreadNew(AdcRead, NULL, &AdcTask_attributes);

  /* USER CODE BEGIN RTOS_THREADS */
  /* add threads, ... */

  /* USER CODE END RTOS_THREADS */

  /* USER CODE BEGIN RTOS_EVENTS */
  /* add events, ... */
  /* USER CODE END RTOS_EVENTS */

  /* Start scheduler */
  osKernelStart();

  /* We should never get here as control is now taken by the scheduler */

  /* Infinite loop */
  /* USER CODE BEGIN WHILE */
  for (;;) {
    /* USER CODE END WHILE */

    /* USER CODE BEGIN 3 */
  }
  /* USER CODE END 3 */
}

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
/* USER CODE BEGIN 4 */
/**
 * The main loop of the program.
 */
void defaultTask() {
	for (;;) {
		// blink with green LED, dimming it
		setPWM(1000, &htim3, TIM_CHANNEL_3);
		osDelay(250);
		setPWM(10000, &htim3, TIM_CHANNEL_3);
		printMeasurements();
		osDelay(250);
	}
}

/**
 * Print message to the default (ST-Link) serial port.
 *
 * @param[in] msg Message to be printed
 * @param[in] len Length of the message
 */
void comprint(char *msg, int len) {
	HAL_USART_Transmit(&husart3, (uint8_t *)msg, len, 100);
}

/**
 * Set pulse time of a timer's channel.
 *
 * @param[in] value Pulse ticks
 * @param[in] timer Timer
 * @param[in] channel Channel
 */
void setPWM(uint16_t value, TIM_HandleTypeDef *timer, uint16_t channel)
{
    TIM_OC_InitTypeDef sConfigOC;

    sConfigOC.OCMode = TIM_OCMODE_PWM1;
    sConfigOC.Pulse = value;
    sConfigOC.OCPolarity = TIM_OCPOLARITY_HIGH;
    sConfigOC.OCFastMode = TIM_OCFAST_DISABLE;
    HAL_TIM_PWM_ConfigChannel(timer, &sConfigOC, channel); // таймер №1, канал №3
    HAL_TIM_PWM_Start(timer, channel);
}

/**
 * Callback on ADC conversion.
 *
 * @param[in] ADC which invoked the conversion
 */
void HAL_ADC_ConvCpltCallback(ADC_HandleTypeDef *hadc) {
	if (hadc->Instance == ADC1) {
		// index to value in window to overwrite old values with new ones
		static uint16_t window_i = 0;
		for (int i = 0; i < SENSOR_LINES; ++i) {
			adcSum[i] -= adcBuffer[i][window_i];
			adcSum[i] += adcData[i];
			adcBuffer[i][window_i] = adcData[i];
		}
		window_i = (window_i + 1) % ADC_WINDOW_SIZE;
	}
}

double adcToVolts(uint32_t adc) {
	return adc / (double) ADC_MAX_VALUE * ADC_MAX_VOLTAGE;
}

int voltToLineNumber(double v, int N) {
	const long double V_S = ADC_MAX_VOLTAGE;
	const long double R = 9180.L;
	const long double R_G = 99500.L;

	long double a = - v / V_S * R * R;
	long double b = R * R_G + v / V_S * (R*R * N + R*R);
	long double c = - R * R_G * N - R * R_G + v / V_S * (R * R_G * N + R * R_G);

	long double D = b * b - 4 * a * c;

	long double x1 = (sqrtl(D) - b) / a / 2.L;
	int n = N + 1 - ((x1 == x1) ? ((int) roundl(x1)) : 7);
	return n;
}

/**
 * Pretty-print a current measurement state of water level.
 */
void printMeasurements() {
	static const int BAR_LENGTH = 40;
	static const char FILL_SIGN[] = "##################################################################";
	static const char EMPTY_SIGN[] = "------------------------------------------------------------------";

	double volts[SENSOR_LINES];
	int activeN[SENSOR_LINES];
	int scaledC = 0;
	double scaled;
	comprint(buff, sprintf(buff, "\033[H"));
	for (int i = 0; i < SENSOR_LINES; ++i) {
		volts[i] = adcToVolts(adcSum[i] / (double) ADC_WINDOW_SIZE);
		activeN[i] = voltToLineNumber(volts[i], lineLength[i]);
		if (activeN[i] > 0) {
			++scaledC;
			float dbound = sens_boundaries[i][1] - sens_boundaries[i][0];
			scaled += activeN[i] * dbound / (float) lineLength[i] + sens_boundaries[i][0];
		}
		comprint(buff, sprintf(
				buff,
				"Line %d: \033[1m%1d\033[m (\033[1m%1.1f\033[m/%1.1f)\033[K\r\n",
				i + 1,
				activeN[i],
				volts[i],
				ADC_MAX_VOLTAGE
		));
	}
	int line_fill = scaledC == 0 ? 0 : (int) (scaled * BAR_LENGTH / (float) scaledC / sens_max);
	comprint(buff, sprintf(buff, "[%.*s%.*s]\r\n", line_fill, FILL_SIGN, (BAR_LENGTH - line_fill), EMPTY_SIGN));
}

/* USER CODE END 4 */

/* USER CODE BEGIN Header_StartDefaultTask */
/**
  * @brief  Function implementing the defaultTask thread.
  * @param  argument: Not used
  * @retval None
  */
/* USER CODE END Header_StartDefaultTask */
void StartDefaultTask(void *argument)
{
  /* USER CODE BEGIN 5 */
  /* Infinite loop */
  defaultTask();

  /* USER CODE END 5 */
}

/* USER CODE BEGIN Header_AdcRead */
/**
* @brief Function implementing the AdcTask thread.
* @param argument: Not used
* @retval None
*/
/* USER CODE END Header_AdcRead */
void AdcRead(void *argument)
{
  /* USER CODE BEGIN AdcRead */
  /* Infinite loop */
  for(;;)
  {
	HAL_ADC_Start_DMA(&hadc1, adcData, SENSOR_LINES);
	osDelay(1);
  }
  /* USER CODE END AdcRead */
}

/**
  * @brief  Period elapsed callback in non blocking mode
  * @note   This function is called  when TIM14 interrupt took place, inside
  * HAL_TIM_IRQHandler(). It makes a direct call to HAL_IncTick() to increment
  * a global variable "uwTick" used as application time base.
  * @param  htim : TIM handle
  * @retval None
  */
void HAL_TIM_PeriodElapsedCallback(TIM_HandleTypeDef *htim)
{
  if (htim->Instance == TIM14)
  {
    HAL_IncTick();
  }
}

/**
  * @brief  This function is executed in case of error occurrence.
  * @retval None
  */
void Error_Handler(void)
{
  /* USER CODE BEGIN Error_Handler_Debug */
  /* User can add his own implementation to report the HAL error return state */
  __disable_irq();
  while (1)
  {
  }
  /* USER CODE END Error_Handler_Debug */
}

#ifdef  USE_FULL_ASSERT
/**
  * @brief  Reports the name of the source file and the source line number
  *         where the assert_param error has occurred.
  * @param  file: pointer to the source file name
  * @param  line: assert_param error line source number
  * @retval None
  */
void assert_failed(uint8_t *file, uint32_t line)
{
  /* USER CODE BEGIN 6 */
  /* User can add his own implementation to report the file name and line number,
     ex: printf("Wrong parameters value: file %s on line %d\r\n", file, line) */
  /* USER CODE END 6 */
}
#endif /* USE_FULL_ASSERT */

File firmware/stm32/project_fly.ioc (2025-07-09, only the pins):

Mcu.UserName=STM32F767ZITx
PA10.GPIO_Label=USB_ID
PA10.Signal=USB_OTG_FS_ID
PA11.GPIO_Label=USB_DM
PA11.Signal=USB_OTG_FS_DM
PA12.GPIO_Label=USB_DP
PA12.Signal=USB_OTG_FS_DP
PA13.GPIO_Label=TMS
PA13.Signal=SYS_JTMS-SWDIO
PA14.GPIO_Label=TCK
PA14.Signal=SYS_JTCK-SWCLK
PA3.Signal=ADCx_IN3
PA8.GPIO_Label=USB_SOF [TP1]
PA8.Signal=USB_OTG_FS_SOF
PA9.GPIO_Label=USB_VBUS
PA9.Signal=USB_OTG_FS_VBUS
PB0.GPIO_Label=LD1 [Green]
PB0.Signal=S_TIM3_CH3
PB12.Signal=USART3_CK
PB14.GPIO_Label=LD3 [Red]
PB14.Signal=GPIO_Output
PB7.GPIO_Label=LD2 [Blue]
PB7.Signal=S_TIM4_CH2
PC0.Signal=ADCx_IN10
PC13.GPIO_Label=USER_Btn [B1]
PC13.Signal=GPXTI13
PD8.Signal=USART3_TX
PD9.Signal=USART3_RX
PG6.GPIO_Label=USB_PowerSwitchOn [STMPS2151STR_EN]
PG6.Signal=GPIO_Output
PG7.GPIO_Label=USB_OverCurrent [STMPS2151STR_FAULT]
PG7.Signal=GPIO_Input

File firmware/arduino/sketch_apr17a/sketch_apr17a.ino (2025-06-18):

#define TRIG 11
#define ECHO 12

void setup() {
  pinMode(TRIG, OUTPUT);
  pinMode(ECHO, INPUT);
  digitalWrite(TRIG, 0);
  Serial.begin(9600);
}

uint32_t sonar() {
  digitalWrite(TRIG, 1);
  delayMicroseconds(10);
  digitalWrite(TRIG, 0);

  uint32_t dur = pulseIn(ECHO, HIGH);
  return dur / 58;
}

void loop() {
  Serial.println(sonar());
  delay(20);
}

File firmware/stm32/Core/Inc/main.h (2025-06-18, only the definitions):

#define USER_Btn_Pin GPIO_PIN_13
#define USER_Btn_GPIO_Port GPIOC
#define LD1_Pin GPIO_PIN_0
#define LD1_GPIO_Port GPIOB
#define LD3_Pin GPIO_PIN_14
#define LD3_GPIO_Port GPIOB
#define USB_PowerSwitchOn_Pin GPIO_PIN_6
#define USB_PowerSwitchOn_GPIO_Port GPIOG
#define USB_OverCurrent_Pin GPIO_PIN_7
#define USB_OverCurrent_GPIO_Port GPIOG
#define USB_SOF_Pin GPIO_PIN_8
#define USB_SOF_GPIO_Port GPIOA
#define USB_VBUS_Pin GPIO_PIN_9
#define USB_VBUS_GPIO_Port GPIOA
#define USB_ID_Pin GPIO_PIN_10
#define USB_ID_GPIO_Port GPIOA
#define USB_DM_Pin GPIO_PIN_11
#define USB_DM_GPIO_Port GPIOA
#define USB_DP_Pin GPIO_PIN_12
#define USB_DP_GPIO_Port GPIOA
#define TMS_Pin GPIO_PIN_13
#define TMS_GPIO_Port GPIOA
#define TCK_Pin GPIO_PIN_14
#define TCK_GPIO_Port GPIOA
#define LD2_Pin GPIO_PIN_7
#define LD2_GPIO_Port GPIOB

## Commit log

2025-06-18 Added testing sketches for arduino configuration of project
2025-06-25 feat(adc): pretty-printing ADC measurements
2025-06-25 feat(adc): RTOS multitasking; ADC measurements averaging
2025-07-02 feat(display): prettier pretty-printing
2025-07-02 refactor(adc): variable sensor lines number
2025-07-02 mvp CAD models + review of float part
    [bottomCap.prt, bottomCap.stp, float - Copie.prt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]
2025-07-03 fix(display): fixed number lengths
    [main.c]
2025-07-03 feat(adc): improved averaging algorithm
2025-07-09 PCB design + review of dimensions
    [PCBassembly.prt, bottomCap.prt, bottomCap.stp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]
2025-07-09 feat(adc): determining number of triggered reed switch
2025-07-09 feat(adc): showing level of water
2025-07-22 new project structure
    [PCBassembly.prt, bottomCap.prt, bottomCap.stp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]

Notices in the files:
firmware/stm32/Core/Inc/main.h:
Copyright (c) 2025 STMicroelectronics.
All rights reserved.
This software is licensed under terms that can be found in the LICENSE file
